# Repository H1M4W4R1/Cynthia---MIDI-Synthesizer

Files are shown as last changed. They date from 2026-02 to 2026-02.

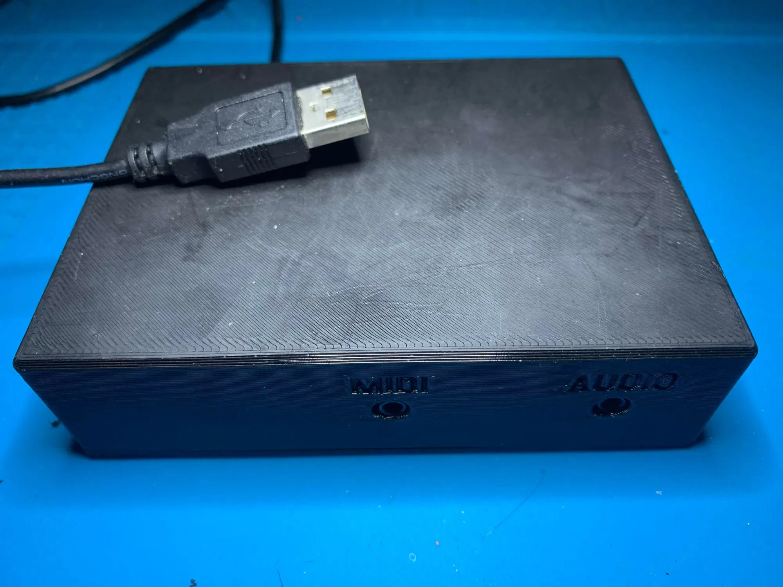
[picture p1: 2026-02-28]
images/photo.webp

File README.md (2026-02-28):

# About
Cynthia is a MIDI Synthesizer supporting most General MIDI devices built around [RP2040 (Raspberry Pi Pico)](https://www.raspberrypi.com/documentation/microcontrollers/pico-series.html) 
and [Adafruit VS1053B](https://www.adafruit.com/product/1381).

It features MIDI input (Type A 3.5mm TR(R)S) to connect controller and USB input. It sends both USB and MIDI input commands
out to VS1053B board which processes them into audible sound. It has no built-in amplifier, so external amp may be needed.

More can be read on [Polish forum Forbot](https://forbot.pl/forum/topic/25873-cynthia-syntezator-midi-trs-a-oraz-usb/).

**All code is AI generated and is mostly functional (there are some bugs, but for my use cases I don't need to fix them)**

# Hardware
* Raspberry Pi Pico (RP2040)
* Adafruit VS1053 Codec
* Two cheap TRRS connectors (red boards)
* A bit of wire
* Two resistors (330R-10K)
* Some 3D printing filament (and a 3D printer of course)
* MicroUSB to USB-A (or C if preferred) cable
* A bit of insulation tape
* 5pcs of M3x16 screws for chassis assembly

# Connections
| **Board A** | **Connection A** | **Board B** | **Connection B** |
|---|---|---|---|
| VS1053B Codec | IO 0 | VS1053B Codec | GND |
| VS1053B Codec | IO 1 | VS1053B Codec | 3V3 |
| Pi Pico | VBUS | VS1053B Codec | VCC |
| Pi Pico | GND | VS1053B Codec | GND |
| Pi Pico | GP12 | VS1053B Codec | RST |
| Pi Pico | GP0 (UART 0 TX)  | VS1053B Codec | RX |
| Pi Pico | GP1 (UART 0 RX)  | Custom MIDI Board | RX |
| Pi Pico | VBUS | Custom MIDI Board | 5V |
| Pi Pico | 3V3 | Custom MIDI Board | 3V3 |
| Pi Pico | GND | Custom MIDI Board | GND |
| VS1053B Codec | L | TRRS 1 | Tip |
| VS1053B Codec | R | TRRS 1 | Ring 1 |
| VS1053B Codec | AGND | TRRS 1 | Sleeve |
| Custom MIDI Board | SINK | TRRS 2 | Tip |
| Custom MIDI Board | SRC | TRRS 2 | Ring 1 |

Of course, you also need to plug-in USB cable into Pico port :)

# Custom MIDI Board
Custom MIDI board used for RX is also available in this repository. It's a simple PC817 coupled with 2N2222 in darlington 
configuration to ensure proper rise/fall times. All necessary resistors are implemented. Board uses THT components and 
0.5mm copper to copper spacing to make it easy to manufacture at home.

# Software
This project comes with two example Python software units that can be used to control this device. 

## Cynthia Controller
This software is used to change instruments (for Cynthia remember to keep channel at 1) for any COM MIDI device connected 
to your PC.

## Cynthia MIDI Player
This software can be used to load and play MIDI music using Cynthia as USB to Audio output interface. Of course, it uses
CDC port which is not standard, but modification to make it work as USB-MIDI device is possible (for author CDC is preferred).

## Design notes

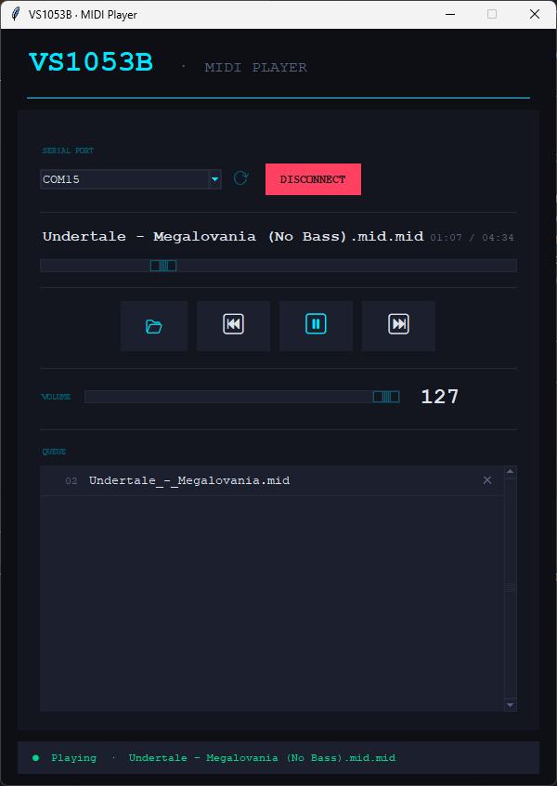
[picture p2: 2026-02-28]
Software/For MIDI Files Playback/screenshot.png

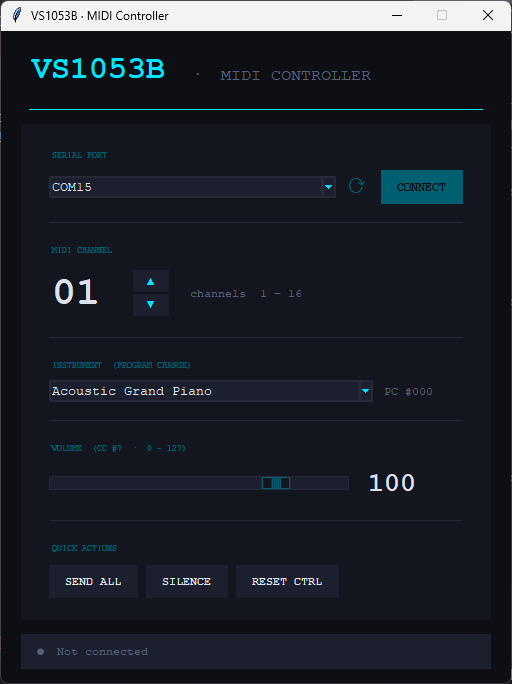
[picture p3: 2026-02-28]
Software/For MIDI Controllers/screenshot.png

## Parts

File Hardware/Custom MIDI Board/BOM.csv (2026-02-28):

Name | Footprint | Value | Quantity | Supplier | Supplier Part | Manufacturer Part | Manufacturer | Designator | LCSC Price | LCSC Stock | JLCPCB Price | JLCPCB Stock
 | DO-41_BD2.4-L4.7-P8.70-D0.9-RD |  | 1 |  |  |  |  | D1 | 1.0218
 | Screw-Hole-M3 |  | 1 |  |  |  |  | SCREW1 | 1.0218
1kΩ | RES-TH_BD2.3-L6.5-P10.50-D0.5 | 1kΩ | 2 | LCSC | C713997 | MF1/4W-1KΩ±1%T52 | 华星机电 | R1,R3 |  |  | 0.0012 | 146046
2N2222A | TO-92-3_L5.2-W4.2-P2.54-L |  | 1 | LCSC | C20616319 | 2N2222A | HXY MOSFET(华轩阳电子) | Q1 |  |  | 0.0032 | 3431
220Ω | RES-TH_BD2.3-L6.5-P10.50-D0.5 | 220Ω | 1 | LCSC | C120039 | CF1/4W-220Ω±5% T | CCO(千志电子) | R2 |  |  | 0.0009 | 8845
HX-XH2.54-3PZZ | CONN-TH_3P-P2.50_HC-XH-3A-G |  | 1 | LCSC | C42391661 | HX-XH2.54-3PZZ | hanxia(韩下) | CN4 |  |  | 0.0016 | 115857
HX-XH2.54-4PZZ | CONN-TH_4P-P2.50-XH2.54-4P |  | 1 | LCSC | C42391662 | HX-XH2.54-4PZZ | hanxia(韩下) | CN2 |  |  | 0.0022 | 160100
PC817C | DIP-4_L4.6-W6.5-P2.54-LS7.6-BL |  | 1 | LCSC | C20612449 | PC817C | KTP(科泰普) | U1 |  |  | 0.0052 | 550

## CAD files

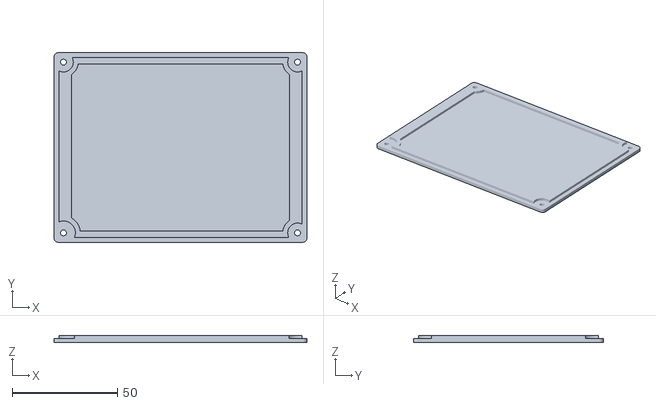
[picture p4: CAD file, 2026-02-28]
STL/Top.stl
120.0 x 90.0 x 3.50

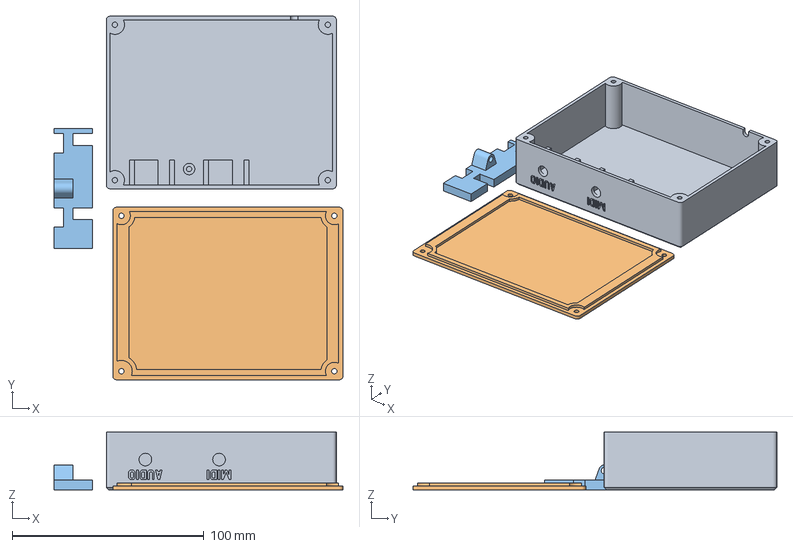
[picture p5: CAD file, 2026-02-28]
STL/Bambulab X1C Plate.3mf
150.7 x 189.6 x 30.0 mm
Bottom.stl
Top.stl
TRRS Blocker.stl

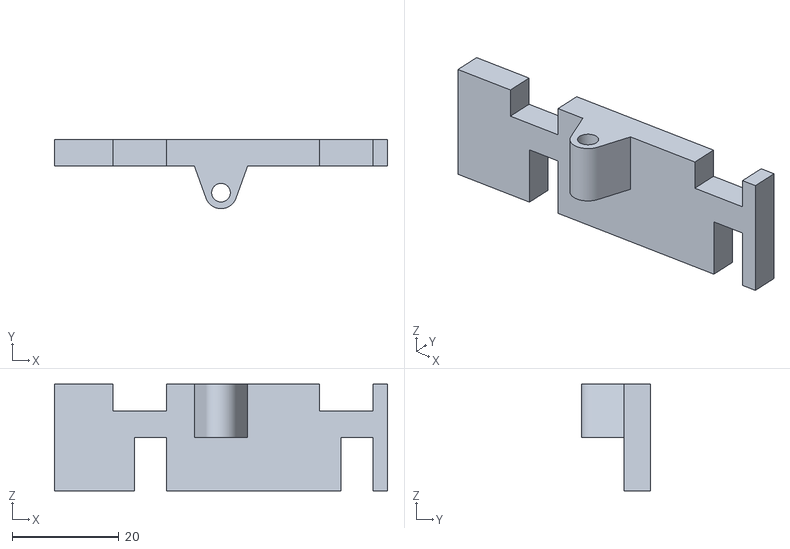
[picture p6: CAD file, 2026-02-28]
STL/TRRS Blocker.stl
62.4 x 13.0 x 20.0

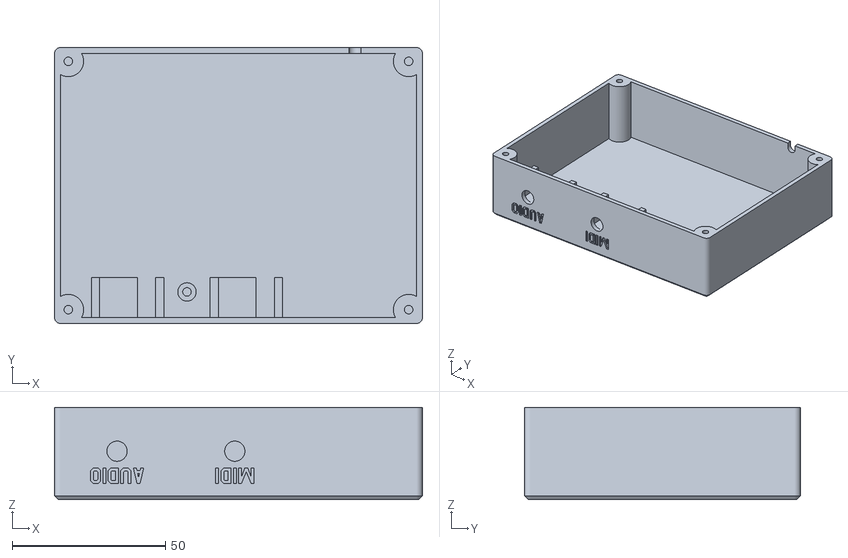
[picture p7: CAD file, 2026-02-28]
STL/Bottom.stl
120.0 x 90.0 x 30.0

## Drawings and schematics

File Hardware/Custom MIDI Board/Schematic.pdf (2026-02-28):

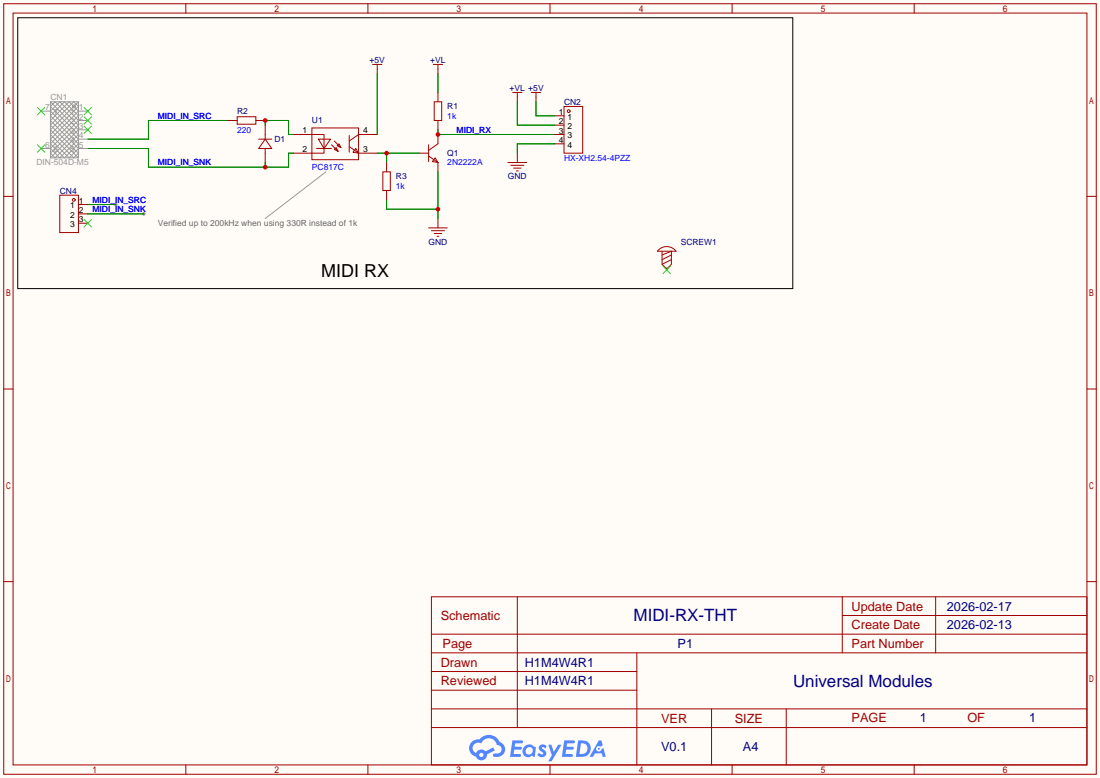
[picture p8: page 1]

Verified up to 200kHz when using 330R instead of 1k

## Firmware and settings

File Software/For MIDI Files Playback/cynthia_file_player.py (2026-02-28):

"""
VS1053B MIDI Player
Reads .mid files and streams them as raw MIDI bytes over a USB CDC serial port.

Requirements:
    pip install pyserial mido

Run:
    python midi_player.py
"""

import tkinter as tk
from tkinter import ttk, filedialog
import serial
import serial.tools.list_ports
import threading
import time
import os
import queue as _queue

# ── optional mido import (auto-install) ──────────────────────────────────────
try:
    import mido
except ImportError:
    import subprocess, sys
    print("[info] mido not found – installing…")
    subprocess.check_call([sys.executable, "-m", "pip", "install", "mido"])
    import mido

try:
    import serial
except ImportError:
    import subprocess, sys
    subprocess.check_call([sys.executable, "-m", "pip", "install", "pyserial"])
    import serial
    import serial.tools.list_ports


# ─────────────────────────────────────────────────────────────────────────────
#  MIDI serial sender
# ─────────────────────────────────────────────────────────────────────────────

class MIDISerial:
    def __init__(self):
        self._port: serial.Serial | None = None
        self._lock = threading.Lock()

    def connect(self, port_name: str, baud: int = 31250) -> None:
        with self._lock:
            if self._port and self._port.is_open:
                self._port.close()
            self._port = serial.Serial(port_name, baud, timeout=1)

    def disconnect(self) -> None:
        with self._lock:
            if self._port and self._port.is_open:
                self._port.close()
            self._port = None

    @property
    def connected(self) -> bool:
        return self._port is not None and self._port.is_open

    def send(self, data: bytes) -> None:
        with self._lock:
            if self._port and self._port.is_open:
                try:
                    self._port.write(data)
                except serial.SerialException:
                    pass

    def all_sound_off(self) -> None:
        for ch in range(16):
            self.send(bytes([0xB0 | ch, 120, 0]))


# ─────────────────────────────────────────────────────────────────────────────
#  MIDI playback engine  (runs in a background thread)
# ─────────────────────────────────────────────────────────────────────────────

class PlayerState:
    STOPPED = "stopped"
    PLAYING = "playing"
    PAUSED  = "paused"


class MIDIPlayer:
    """
    Reads a mido MidiFile and streams MIDI bytes with correct timing.
    Supports: play, pause/resume, rewind, seek (silent), skip, volume.

    Design: a single background thread owns all playback.
    Any operation that changes position (seek/rewind/load) stops the current
    thread synchronously via _stop_thread(), then restarts from the new
    position.  This avoids every race condition that arises from trying to
    redirect a running thread mid-flight.
    """

    def __init__(self, midi_serial: MIDISerial):
        self._ser  = midi_serial

        # Protected by _lock
        self._state    = PlayerState.STOPPED
        self._messages : list[tuple[float, bytes]] = []
        self._duration : float = 0.0
        self._pos      : float = 0.0          # start position for next play()
        self._volume   : float = 1.0
        self._lock     = threading.Lock()

        # Thread control
        self._thread   : threading.Thread | None = None
        self._stop_evt = threading.Event()    # set → thread must exit ASAP
        self._pause_evt= threading.Event()
        self._pause_evt.set()                 # clear = paused, set = running

        # Callbacks (called from bg thread; must be set before play())
        self.on_position: callable | None = None   # (pos_s, dur_s) → None
        self.on_finished: callable | None = None   # () → None

    # ── public API ────────────────────────────────────────────────────────────

    @property
    def state(self) -> str:
        return self._state

    @property
    def duration(self) -> float:
        return self._duration

    @property
    def position(self) -> float:
        return self._pos

    def load(self, path: str) -> float:
        """Stop playback, load a new file, reset position. Returns duration."""
        self._stop_thread()
        mid      = mido.MidiFile(path)
        messages = self._flatten(mid)
        with self._lock:
            self._messages = messages
            self._duration = messages[-1][0] if messages else 0.0
            self._pos      = 0.0
            self._state    = PlayerState.STOPPED
        return self._duration

    def play(self) -> None:
        """Start or resume playback."""
        with self._lock:
            if self._state == PlayerState.PLAYING:
                return
            if self._state == PlayerState.PAUSED:
                self._state = PlayerState.PLAYING
                self._pause_evt.set()
                return
            # STOPPED → launch thread from current _pos
            self._state = PlayerState.PLAYING
        self._launch_thread()

    def pause(self) -> None:
        with self._lock:
            if self._state != PlayerState.PLAYING:
                return
            self._state = PlayerState.PAUSED
        self._pause_evt.clear()
        self._ser.all_sound_off()

    def stop(self) -> None:
        """Stop and reset position to 0."""
        self._stop_thread()
        with self._lock:
            self._pos   = 0.0
            self._state = PlayerState.STOPPED
        self._ser.all_sound_off()

    def seek(self, seconds: float) -> None:
        """
        Jump to position silently:
        1. Stop current thread.
        2. Update _pos.
        3. Restart thread if we were playing, otherwise stay stopped.
        """
        with self._lock:
            was_playing = (self._state == PlayerState.PLAYING)
            was_paused  = (self._state == PlayerState.PAUSED)
        self._stop_thread()
        with self._lock:
            self._pos = max(0.0, min(seconds, self._duration))
        self._ser.all_sound_off()
        if was_playing or was_paused:
            with self._lock:
                self._state = PlayerState.PLAYING
            self._launch_thread()

    def rewind(self) -> None:
        self.seek(0.0)

    def set_volume(self, v: float) -> None:
        with self._lock:
            self._volume = max(0.0, min(1.0, v))

    def skip(self) -> None:
        """Stop current track; caller decides what to play next."""
        self._stop_thread()
        with self._lock:
            self._pos   = 0.0
            self._state = PlayerState.STOPPED
        self._ser.all_sound_off()

    # ── thread management ─────────────────────────────────────────────────────

    def _stop_thread(self) -> None:
        """Signal the bg thread to stop and block until it exits."""
        self._stop_evt.set()
        self._pause_evt.set()   # unblock if sleeping in pause
        if self._thread and self._thread.is_alive():
            self._thread.join(timeout=2.0)
        self._thread   = None
        self._stop_evt.clear()

    def _launch_thread(self) -> None:
        self._stop_evt.clear()
        self._pause_evt.set()   # ensure not paused on start
        self._thread = threading.Thread(target=self._run, daemon=True)
        self._thread.start()

    # ── playback loop ─────────────────────────────────────────────────────────

    def _run(self) -> None:
        with self._lock:
            messages = self._messages[:]
            start_pos = self._pos
            duration  = self._duration

        # Find the first message at or after start_pos (silent seek already done)
        idx = self._bisect(messages, start_pos)
        t0  = time.perf_counter() - start_pos   # wall-clock anchor

        i = idx
        while i < len(messages):
            if self._stop_evt.is_set():
                break

            msg_time, raw = messages[i]

            # ── wait loop: sleep in small increments, honouring pause/stop ──
            while True:
                if self._stop_evt.is_set():
                    break

                # Pause: block here without burning CPU
                if not self._pause_evt.is_set():
                    # Record position before blocking
                    with self._lock:
                        self._pos = msg_time
                    self._pause_evt.wait()
                    if self._stop_evt.is_set():
                        break
                    # Re-anchor wall clock after unpause
                    t0 = time.perf_counter() - msg_time

                elapsed = time.perf_counter() - t0
                delta   = msg_time - elapsed
                if delta <= 0:
                    break
                time.sleep(min(delta, 0.002))   # 2 ms granularity

            if self._stop_evt.is_set():
                with self._lock:
                    self._pos = msg_time
                break

            # ── send ──────────────────────────────────────────────────────
            self._ser.send(self._apply_volume(raw))

            # ── update reported position ───────────────────────────────────
            with self._lock:
                self._pos = msg_time
            if self.on_position:
                self.on_position(msg_time, duration)

            i += 1

        # ── thread exiting ────────────────────────────────────────────────
        if not self._stop_evt.is_set():
            # Reached end of track naturally
            with self._lock:
                self._state = PlayerState.STOPPED
                self._pos   = 0.0
            self._ser.all_sound_off()
            if self.on_finished:
                self.on_finished()

    # ── helpers ───────────────────────────────────────────────────────────────

    @staticmethod
    def _bisect(messages: list, pos: float) -> int:
        """Return index of first message with time >= pos."""
        lo, hi = 0, len(messages)
        while lo < hi:
            mid = (lo + hi) // 2
            if messages[mid][0] < pos:
                lo = mid + 1
            else:
                hi = mid
        return lo

    @staticmethod
    def _flatten(mid: mido.MidiFile) -> list[tuple[float, bytes]]:
        """
        Merge all tracks → sorted (absolute_seconds, raw_bytes) list.

        Steps:
          1. Accumulate each track's delta-ticks into absolute ticks.
          2. Merge & sort by absolute tick.
          3. Walk in tick order, tracking tempo changes to convert ticks→seconds.
        """
        ticks_per_beat = mid.ticks_per_beat

        # Step 1 & 2: absolute-tick merge
        merged: list[tuple[int, object]] = []
        for track in mid.tracks:
            abs_tick = 0
            for msg in track:
                abs_tick += msg.time        # delta ticks
                merged.append((abs_tick, msg))
        merged.sort(key=lambda x: x[0])

        # Step 3: ticks → seconds with live tempo map
        tempo      = 500_000    # µs/beat  (120 BPM default)
        last_tick  = 0
        elapsed_us = 0.0
        result     = []

        for abs_tick, msg in merged:
            delta_tick  = abs_tick - last_tick
            elapsed_us += delta_tick * (tempo / ticks_per_beat)
            last_tick   = abs_tick

            if msg.is_meta:
                if msg.type == "set_tempo":
                    tempo = msg.tempo
                continue

            raw = bytes(msg.bytes())
            if raw:
                result.append((elapsed_us / 1_000_000.0, raw))

        return result

    def _apply_volume(self, raw: bytes) -> bytes:
        """Scale CC#7 (main volume) by the current volume factor."""
        if len(raw) >= 3 and (raw[0] & 0xF0) == 0xB0 and raw[1] == 7:
            with self._lock:
                vol = self._volume
            scaled = max(0, min(127, int(raw[2] * vol)))
            return bytes([raw[0], raw[1], scaled])
        return raw


# ─────────────────────────────────────────────────────────────────────────────
#  Colour palette  (matches midi_controller.py)
# ─────────────────────────────────────────────────────────────────────────────

C_BG        = "#0d0f14"
C_PANEL     = "#13161f"
C_CARD      = "#1c202e"
C_BORDER    = "#262a38"
C_ACCENT    = "#00e5ff"
C_ACCENT2   = "#005f70"
C_TEXT      = "#dde3ec"
C_MUTED     = "#55607a"
C_OK        = "#00d68f"
C_ERR       = "#ff4060"
C_TROUGH    = "#1c202e"
C_HIGHLIGHT = "#1e3540"   # selected queue row
C_PLAYING   = "#002a35"   # currently-playing row tint

FONT_MONO   = ("Courier New", 10)
FONT_MONO_S = ("Courier New", 8)
FONT_MONO_M = ("Courier New", 12, "bold")
FONT_MONO_L = ("Courier New", 18, "bold")
FONT_MONO_XL= ("Courier New", 26, "bold")


# ─────────────────────────────────────────────────────────────────────────────
#  Reusable widgets
# ─────────────────────────────────────────────────────────────────────────────

class Divider(tk.Frame):
    def __init__(self, parent, **kw):
        super().__init__(parent, bg=C_BORDER, height=1, **kw)


class SectionLabel(tk.Label):
    def __init__(self, parent, text, **kw):
        super().__init__(parent, text=text.upper(),
                         font=("Courier New", 7, "bold"),
                         bg=C_PANEL, fg=C_ACCENT2, anchor="w", **kw)


class Tooltip:
    def __init__(self, widget: tk.Widget, text: str):
        widget.bind("<Enter>", lambda _: self._show(widget))
        widget.bind("<Leave>", lambda _: self._hide())
        self._text = text
        self._win: tk.Toplevel | None = None

    def _show(self, widget):
        x = widget.winfo_rootx() + 24
        y = widget.winfo_rooty() + widget.winfo_height() + 4
        self._win = tw = tk.Toplevel(widget)
        tw.wm_overrideredirect(True)
        tw.wm_geometry(f"+{x}+{y}")
        tk.Label(tw, text=self._text, font=FONT_MONO_S,
                 bg=C_CARD, fg=C_MUTED, bd=1, relief="flat",
                 highlightbackground=C_BORDER, highlightthickness=1,
                 padx=8, pady=4).pack()

    def _hide(self):
        if self._win:
            self._win.destroy()
            self._win = None


class StatusBar(tk.Frame):
    def __init__(self, parent, **kw):
        super().__init__(parent, bg=C_CARD, pady=6, **kw)
        self._dot = tk.Label(self, text="●", font=("Courier New", 11),
                             bg=C_CARD, fg=C_MUTED)
        self._dot.pack(side="left", padx=(12, 6))
        self._msg = tk.Label(self, text="No file loaded",
                             font=FONT_MONO_S, bg=C_CARD, fg=C_MUTED, anchor="w")
        self._msg.pack(side="left", fill="x", expand=True)

    def ok(self, text):
        self._dot.config(fg=C_OK);  self._msg.config(text=text, fg=C_OK)

    def err(self, text):
        self._dot.config(fg=C_ERR); self._msg.config(text=text, fg=C_ERR)

    def info(self, text):
        self._dot.config(fg=C_MUTED); self._msg.config(text=text, fg=C_MUTED)


# ─────────────────────────────────────────────────────────────────────────────
#  Queue list widget
# ─────────────────────────────────────────────────────────────────────────────

class QueueList(tk.Frame):
    """Scrollable list of queued MIDI files."""

    ROW_H = 32

    def __init__(self, parent, on_double_click=None, **kw):
        super().__init__(parent, bg=C_CARD, **kw)
        self._on_dc   = on_double_click
        self._items   : list[str] = []   # full paths
        self._playing : int       = -1   # index currently playing
        self._selected: int       = -1

        self._canvas = tk.Canvas(self, bg=C_CARD, bd=0, highlightthickness=0,
                                 width=500)
        self._scroll = ttk.Scrollbar(self, orient="vertical",
                                     command=self._canvas.yview)
        self._canvas.configure(yscrollcommand=self._scroll.set)

        self._inner = tk.Frame(self._canvas, bg=C_CARD)
        self._window = self._canvas.create_window((0, 0), window=self._inner,
                                                   anchor="nw")

        self._canvas.pack(side="left", fill="both", expand=True)
        self._scroll.pack(side="right", fill="y")

        self._inner.bind("<Configure>", self._on_inner_configure)
        self._canvas.bind("<Configure>", self._on_canvas_configure)
        self._canvas.bind("<MouseWheel>",
                          lambda e: self._canvas.yview_scroll(-1*(e.delta//120), "units"))

    def _on_inner_configure(self, _=None):
        self._canvas.configure(scrollregion=self._canvas.bbox("all"))

    def _on_canvas_configure(self, e):
        self._canvas.itemconfig(self._window, width=e.width)

    def add(self, path: str):
        idx = len(self._items)
        self._items.append(path)
        self._make_row(idx)

    def _make_row(self, idx: int):
        path  = self._items[idx]
        name  = os.path.basename(path)
        frame = tk.Frame(self._inner, bg=C_CARD, height=self.ROW_H,
                         cursor="hand2")
        frame.pack(fill="x", expand=True)
        frame.pack_propagate(False)

        # index label
        num = tk.Label(frame, text=f"{idx+1:02d}",
                       font=FONT_MONO_S, bg=C_CARD, fg=C_MUTED,
                       width=4, anchor="e")
        num.pack(side="left", padx=(10, 6))

        # file name
        name_lbl = tk.Label(frame, text=name, font=FONT_MONO,
                             bg=C_CARD, fg=C_TEXT, anchor="w")
        name_lbl.pack(side="left", fill="x", expand=True)

        # remove button
        rm = tk.Label(frame, text="✕", font=("Courier New", 9),
                      bg=C_CARD, fg=C_MUTED, cursor="hand2", padx=10)
        rm.pack(side="right")

        # separator
        sep = tk.Frame(self._inner, bg=C_BORDER, height=1)
        sep.pack(fill="x")

        widgets = (frame, num, name_lbl, rm, sep)

        # bindings
        for w in (frame, num, name_lbl, rm):
            w.bind("<Button-1>",   lambda e, i=idx: self._select(i))
            w.bind("<Double-1>",   lambda e, i=idx: self._double(i))
        rm.bind("<Button-1>",      lambda e, i=idx, ws=widgets: self._remove(i, ws))
        rm.bind("<Enter>",         lambda e, w=rm: w.config(fg=C_ERR))
        rm.bind("<Leave>",         lambda e, w=rm: w.config(fg=C_MUTED))

        self._apply_row_style(idx, frame, num, name_lbl)

        # store for later style updates
        if not hasattr(self, '_rows'):
            self._rows = []
        self._rows.append((frame, num, name_lbl, rm, sep))

    def _select(self, idx: int):
        self._selected = idx
        self._refresh_styles()

    def _double(self, idx: int):
        self._select(idx)
        if self._on_dc:
            self._on_dc(idx, self._items[idx])

    def _remove(self, idx: int, widgets):
        if idx < len(self._items):
            self._items.pop(idx)
        for w in widgets:
            w.destroy()
        if hasattr(self, '_rows') and idx < len(self._rows):
            self._rows.pop(idx)
        # re-number remaining
        self._renumber()

    def _renumber(self):
        if not hasattr(self, '_rows'):
            return
        for i, (frame, num, name_lbl, rm, sep) in enumerate(self._rows):
            try:
                num.config(text=f"{i+1:02d}")
            except tk.TclError:
                pass

    def _apply_row_style(self, idx, frame, num, name_lbl):
        if idx == self._playing:
            bg, fg = C_PLAYING, C_ACCENT
        elif idx == self._selected:
            bg, fg = C_HIGHLIGHT, C_TEXT
        else:
            bg, fg = C_CARD, C_TEXT
            num_fg = C_MUTED
            num.config(bg=bg, fg=num_fg)
        for w in (frame, name_lbl):
            w.config(bg=bg)
        name_lbl.config(fg=fg)

    def _refresh_styles(self):
        if not hasattr(self, '_rows'):
            return
        for i, (frame, num, name_lbl, rm, sep) in enumerate(self._rows):
            try:
                self._apply_row_style(i, frame, num, name_lbl)
            except tk.TclError:
                pass

    def set_playing(self, idx: int):
        self._playing = idx
        self._refresh_styles()

    def clear_playing(self):
        self._playing = -1
        self._refresh_styles()

    @property
    def items(self) -> list[str]:
        return self._items[:]

    @property
    def selected(self) -> int:
        return self._selected

    def __len__(self):
        return len(self._items)


# ─────────────────────────────────────────────────────────────────────────────
#  Main application
# ─────────────────────────────────────────────────────────────────────────────

def fmt_time(s: float) -> str:
    s = max(0.0, s)
    m = int(s) // 60
    return f"{m:02d}:{int(s) % 60:02d}"
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

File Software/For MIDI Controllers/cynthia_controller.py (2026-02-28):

"""
VS1053B MIDI Device Controller
USB CDC Serial Interface

Requirements: pyserial  (`pip install pyserial`)
Run:          python midi_controller.py
"""

import tkinter as tk
from tkinter import ttk
import serial
import serial.tools.list_ports
import threading
import time

# ─────────────────────────────────────────────────────────────────────────────
#  General MIDI instrument list  (VS1053B GM bank, program numbers 0–127)
# ─────────────────────────────────────────────────────────────────────────────
GM_INSTRUMENTS = [
    # Piano
    "Acoustic Grand Piano", "Bright Acoustic Piano", "Electric Grand Piano",
    "Honky-tonk Piano", "Electric Piano 1", "Electric Piano 2",
    "Harpsichord", "Clavinet",
    # Chromatic Perc
    "Celesta", "Glockenspiel", "Music Box", "Vibraphone",
    "Marimba", "Xylophone", "Tubular Bells", "Dulcimer",
    # Organ
    "Drawbar Organ", "Percussive Organ", "Rock Organ", "Church Organ",
    "Reed Organ", "Accordion", "Harmonica", "Tango Accordion",
    # Guitar
    "Nylon String Guitar", "Steel String Guitar", "Jazz Guitar",
    "Clean Electric Guitar", "Muted Electric Guitar", "Overdriven Guitar",
    "Distortion Guitar", "Guitar Harmonics",
    # Bass
    "Acoustic Bass", "Fingered Electric Bass", "Picked Electric Bass",
    "Fretless Bass", "Slap Bass 1", "Slap Bass 2",
    "Synth Bass 1", "Synth Bass 2",
    # Strings
    "Violin", "Viola", "Cello", "Contrabass",
    "Tremolo Strings", "Pizzicato Strings", "Orchestral Harp", "Timpani",
    # Ensemble
    "String Ensemble 1", "String Ensemble 2", "Synth Strings 1", "Synth Strings 2",
    "Choir Aahs", "Voice Oohs", "Synth Voice", "Orchestra Hit",
    # Brass
    "Trumpet", "Trombone", "Tuba", "Muted Trumpet",
    "French Horn", "Brass Section", "Synth Brass 1", "Synth Brass 2",
    # Reed
    "Soprano Sax", "Alto Sax", "Tenor Sax", "Baritone Sax",
    "Oboe", "English Horn", "Bassoon", "Clarinet",
    # Pipe
    "Piccolo", "Flute", "Recorder", "Pan Flute",
    "Blown Bottle", "Shakuhachi", "Whistle", "Ocarina",
    # Synth Lead
    "Square Wave Lead", "Sawtooth Lead", "Calliope Lead", "Chiff Lead",
    "Charang Lead", "Voice Lead", "Fifths Lead", "Bass+Lead",
    # Synth Pad
    "New Age Pad", "Warm Pad", "Polysynth Pad", "Choir Pad",
    "Bowed Pad", "Metallic Pad", "Halo Pad", "Sweep Pad",
    # Synth FX
    "Rain FX", "Soundtrack FX", "Crystal FX", "Atmosphere FX",
    "Brightness FX", "Goblins FX", "Echoes FX", "Sci-fi FX",
    # Ethnic
    "Sitar", "Banjo", "Shamisen", "Koto",
    "Kalimba", "Bag Pipe", "Fiddle", "Shanai",
    # Percussive
    "Tinkle Bell", "Agogo", "Steel Drums", "Woodblock",
    "Taiko Drum", "Melodic Tom", "Synth Drum", "Reverse Cymbal",
    # Sound Effects
    "Guitar Fret Noise", "Breath Noise", "Seashore", "Bird Tweet",
    "Telephone Ring", "Helicopter", "Applause", "Gunshot",
]

# ─────────────────────────────────────────────────────────────────────────────
#  Serial / MIDI helper
# ─────────────────────────────────────────────────────────────────────────────

class MIDISerial:
    """Thread-safe wrapper for sending raw MIDI bytes over a serial port."""

    def __init__(self):
        self._port: serial.Serial | None = None
        self._lock = threading.Lock()

    # ── connection ────────────────────────────────────────────────────────────

    def connect(self, port_name: str, baud: int = 31250) -> None:
        """Open (or re-open) a serial port. Raises serial.SerialException on failure."""
        with self._lock:
            if self._port and self._port.is_open:
                self._port.close()
            self._port = serial.Serial(port_name, baud, timeout=1)

    def disconnect(self) -> None:
        with self._lock:
            if self._port and self._port.is_open:
                self._port.close()
            self._port = None

    @property
    def connected(self) -> bool:
        return self._port is not None and self._port.is_open

    # ── raw write ─────────────────────────────────────────────────────────────

    def send(self, data: bytes) -> None:
        with self._lock:
            if self._port and self._port.is_open:
                self._port.write(data)

    # ── MIDI messages ─────────────────────────────────────────────────────────

    def program_change(self, channel: int, program: int) -> None:
        """Cx pp  –  select instrument.  channel 0-15, program 0-127."""
        self.send(bytes([0xC0 | (channel & 0x0F), program & 0x7F]))

    def control_change(self, channel: int, control: int, value: int) -> None:
        """Bx cc vv  –  generic CC.  channel 0-15, control 0-127, value 0-127."""
        self.send(bytes([0xB0 | (channel & 0x0F), control & 0x7F, value & 0x7F]))

    def set_volume(self, channel: int, volume: int) -> None:
        """CC #7 = main channel volume (0-127)."""
        self.control_change(channel, 7, volume)

    def all_sound_off(self, channel: int) -> None:
        """CC #120 = All Sound Off."""
        self.control_change(channel, 120, 0)

    def reset_all_controllers(self, channel: int) -> None:
        """CC #121 = Reset All Controllers."""
        self.control_change(channel, 121, 0)


# ─────────────────────────────────────────────────────────────────────────────
#  Colour palette & shared fonts
# ─────────────────────────────────────────────────────────────────────────────

C_BG        = "#0d0f14"
C_PANEL     = "#13161f"
C_CARD      = "#1c202e"
C_BORDER    = "#262a38"
C_ACCENT    = "#00e5ff"
C_ACCENT2   = "#005f70"
C_TEXT      = "#dde3ec"
C_MUTED     = "#55607a"
C_OK        = "#00d68f"
C_ERR       = "#ff4060"
C_TROUGH    = "#1c202e"

FONT_MONO   = ("Courier New", 10)
FONT_MONO_S = ("Courier New", 8)
FONT_MONO_L = ("Courier New", 20, "bold")
FONT_MONO_XL= ("Courier New", 30, "bold")


# ─────────────────────────────────────────────────────────────────────────────
#  Reusable widgets
# ─────────────────────────────────────────────────────────────────────────────

class Divider(tk.Frame):
    def __init__(self, parent, **kw):
        super().__init__(parent, bg=C_BORDER, height=1, **kw)


class SectionLabel(tk.Label):
    def __init__(self, parent, text, **kw):
        super().__init__(parent, text=text.upper(),
                         font=("Courier New", 7, "bold"),
                         bg=C_PANEL, fg=C_ACCENT2,
                         anchor="w", **kw)
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

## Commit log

2026-02-28 Uploaded initial version files.
    [BOM.csv, Bambulab X1C Plate.3mf, Bottom.stl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]
2026-02-28 Fixed MIDI time slider issues.
    [cynthia_file_player.py]
